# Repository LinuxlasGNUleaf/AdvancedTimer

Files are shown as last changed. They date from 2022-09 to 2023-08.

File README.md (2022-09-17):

# Advanced Timer 
This project aims to create a digital hourglass to be displayed on a LED-matrix.
The 3D-printed casing for this hourglass is fitted with dials to set the timer and change settings and a buzzer to sound an alarm tone when the timer is finished.
An Arduino Nano controls the simulation and is connected to the input dials as well.

# CAD part
The casing was designed in Autodesk Fusion 360 and consists of two main parts: The display case, featuring a 7-segment display and the LED-matrix, and the control case, housing the Arduino, power supply and input dials.
The different parts of each case and the finished casings themselves are to be 3d-printed and fitted with M3x5,7mm threaded inserts and screwed together using countersunk M3x10 and M3x14 screws.

# Assembly part
The LED-matrix consists of two daisy-chained modules using the SPI bus. These modules should be glued together (hot glue works well) and the SPI bus extended to the second module before assembly of the case starts. 
Data and power cables for the two modules inside the display casing have to be routed into the control casing via a small connector hole in the perimeter of the casings. The power supply, consisting of a 9V battery block, can be connected to the VIN/GND ports of the Arduino via the ON/OFF switch. The Arduino will transform the +9V to +5V for internal use and for external consumers like in our case. Since every breakout board used in this build requires a GND and +5V connection, a dedicated terminal for each of these is recommended. A WAGO 5-port splicing connector is sufficient and the control case has room for two (one for each of the aforementioned potentials). Once the rotary encoder (= input dial) has been connected to the power connectors as well and all data cables have been connected to the specified ports of the Arduino, it can be powered either via internal power source using the ON/OFF switch or using the exposed USB port of the Arduino. The latter will also be used to flash the program.

# Programming 
The firmware for this project was written in C++, using the platformio framework. The Arduino can be flashed without disassembling the case using the exposed USB port like mentioned above.
The behavior of the firmware can be changed in `config.h`.

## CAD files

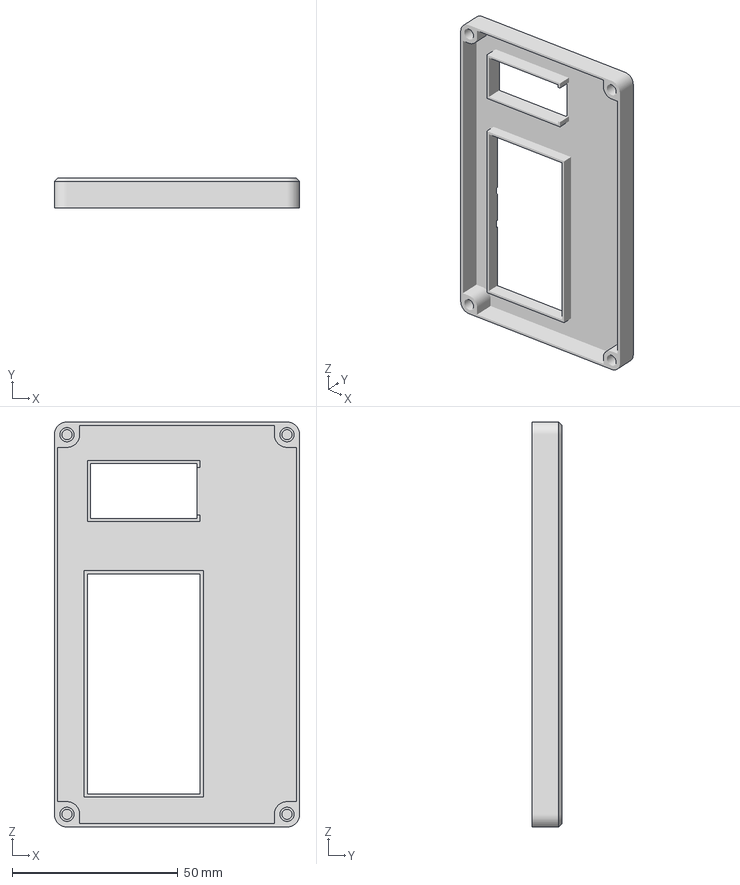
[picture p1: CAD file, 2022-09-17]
3d-print/FrontCasing.3mf
74.0 x 9.00 x 122.1 mm

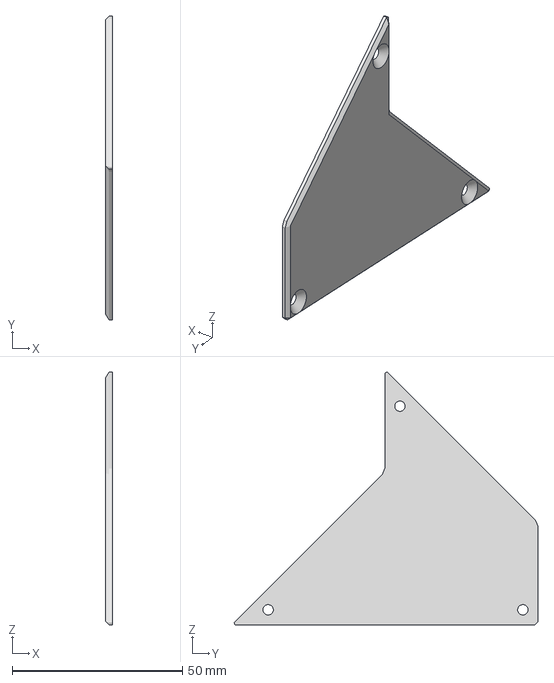
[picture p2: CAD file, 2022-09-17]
3d-print/SideCover.3mf
2.00 x 89.3 x 74.3 mm

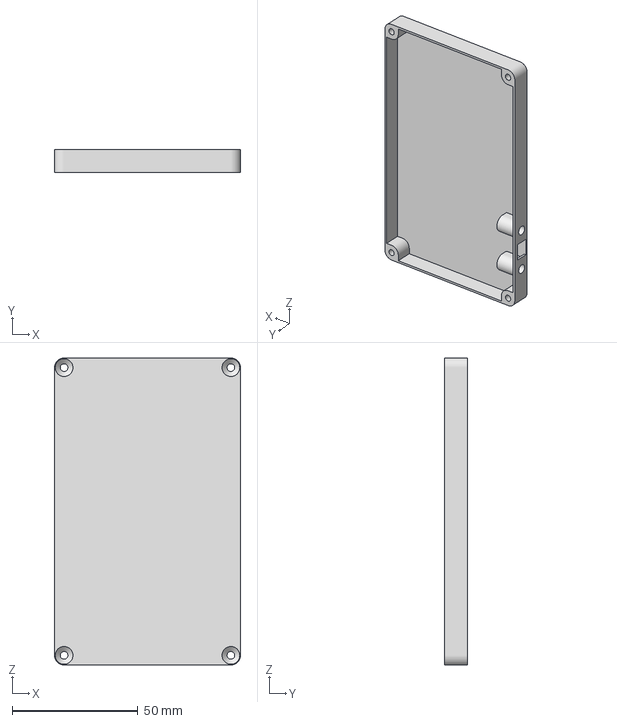
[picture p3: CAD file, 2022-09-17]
3d-print/BackCasing.3mf
74.0 x 9.00 x 122.1 mm

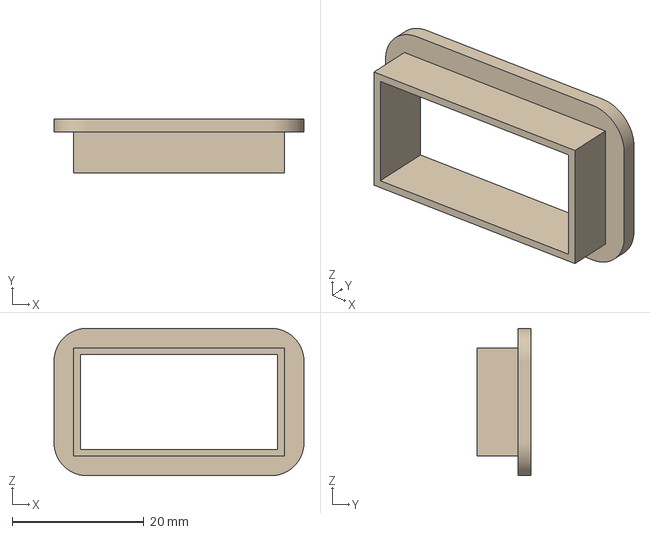
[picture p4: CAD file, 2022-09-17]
3d-print/SegmentCover.3mf
38.0 x 8.20 x 22.4 mm

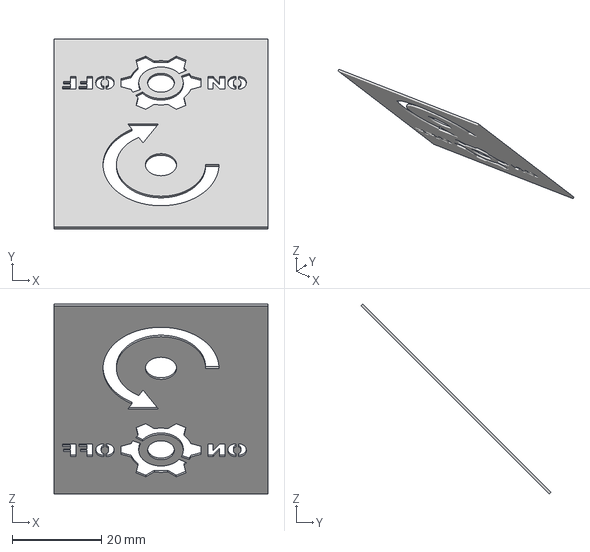
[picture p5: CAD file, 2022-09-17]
3d-print/TextCover.3mf
48.0 x 42.5 x 42.5 mm

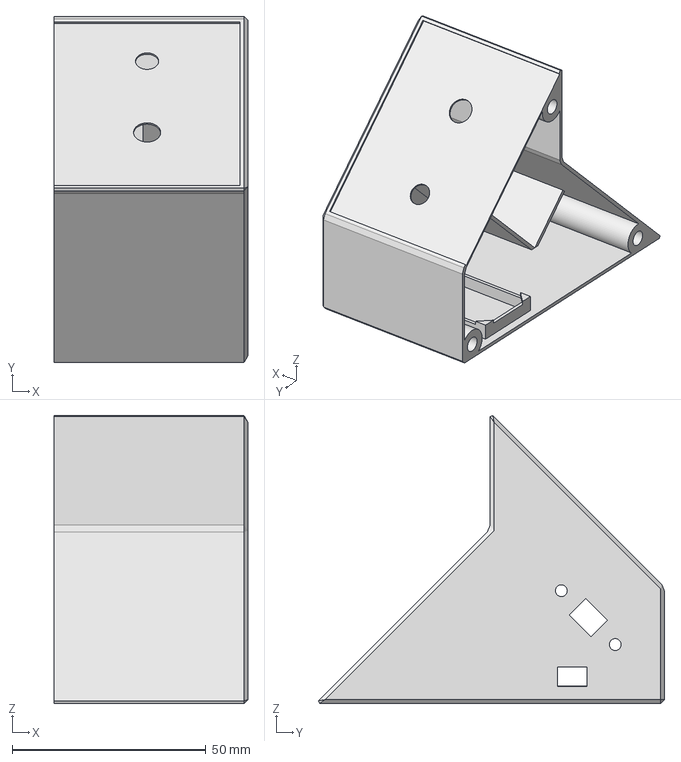
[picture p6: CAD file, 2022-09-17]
3d-print/SideHousing.3mf
50.0 x 89.3 x 74.3 mm

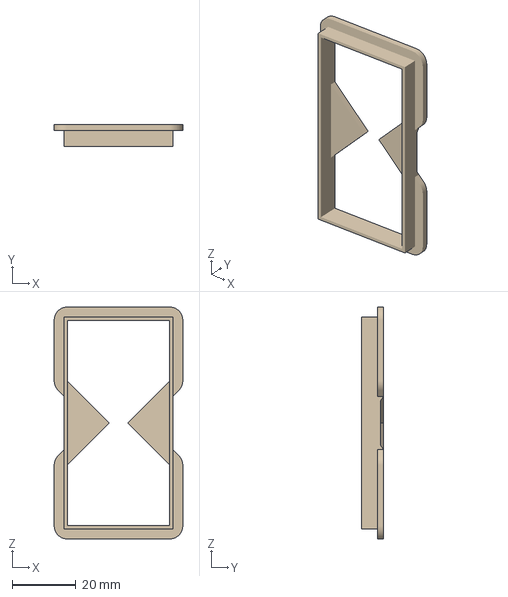
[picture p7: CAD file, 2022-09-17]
3d-print/Cover.3mf
40.2 x 7.00 x 72.5 mm

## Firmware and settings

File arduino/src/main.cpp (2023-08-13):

#include <Arduino.h>
#include <config.h>
#include <DisplayHandler.h>
#include <TimerHandler.h>

TimerHandler time_handler;
DisplayHandler display_handler;

void tickPosition()
{
  time_handler.enc->tick(); // just call tick() to check the timer_state.
}

void setup()
{
  randomSeed(analogRead(0));

#if DEBUG
  Serial.begin(SERIAL_SPEED);
#endif

  time_handler = TimerHandler();
  display_handler = DisplayHandler();

  // initialize objects & attach interrupts
  time_handler.init(tickPosition);
  display_handler.init();

  // fill upper half of hourglass
  display_handler.setup(SIM_FILL);
  while (!display_handler.is_full || !display_handler.sim_idle || time_handler.timer_state != RUNNING)
  {
    display_handler.tick(0);
    time_handler.tick();
  }
  display_handler.setup(SIM_RUNNING);
}

float progress;
void loop()
{
  while (!display_handler.is_full || !display_handler.sim_idle || time_handler.timer_state == RUNNING)
  {
    progress = time_handler.calculateTimerProgress();
    display_handler.tick(progress);
    time_handler.tick();
  }
  while (time_handler.timer_state == FINISHED)
  {
    time_handler.tick();
  }
  time_handler.resetTimerHandler();
  display_handler.setup(SIM_RELOADING);
  while (!display_handler.is_full || !display_handler.sim_idle || time_handler.timer_state != RUNNING)
  {
    display_handler.tick(0);
    time_handler.tick();
  }
  display_handler.setup(SIM_RUNNING);
}

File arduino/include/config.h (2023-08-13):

#ifndef CONFIG_H
#define CONFIG_H

// CONFIGURATION FILE
#include <MD_MAX72xx.h>
#include <TM1637Display.h>
#include <RotaryEncoder.h>
#include <EEPROM.h>
#include <hash.h>
#include <ezBuzzer.h>

// ======> PREPROCESSOR MACROS
#define DEBUG 1

#if DEBUG
#define SPRINT(msg) Serial.print(msg)
#define SPRINTLN(msg) Serial.println(msg)
#else
#define SPRINT(msg)
#define SPRINTLN(msg) 
#endif

// ======> CPP MACROS

#define INTERVAL_PASSED(start_time, interval, current_time) ((start_time + interval) < current_time)

// ======> HARDWARE / WIRING CONFIGURATION

    // ==> LED MATRIX
        
        // MATRIX SPI BUS: DIO, CLK, CS
        const int MAT_SPI_BUS[] = {11, 13, 10};

        // MODULE WIDTH
        const int MAT_WIDTH = 8;

        // MODULE COUNT
        const int MAT_MODULE_COUNT = 2;

        // MATRIX HW_TYPE
        const MD_MAX72XX::moduleType_t MAT_TYPE = MD_MAX72XX::FC16_HW;

        // MATRIX LED BRIGHTNESS
        const int MAT_BRIGHTNESS = 0;

        // MATRIX DAISY CHAIN SETUP
        /*
        *   HARDWARE LAYOUT
        *   
        * X/Y | 15 | 14 | 13 | 12 | 11 | 10 |  9 |  8 |
        *  ---+----+----+----+----+----+----+----+----+
        *  0  | ▢ | ▢ | ▢ | ▢ | ▢ | ▢ | ▢ | ▢ |
        *  1  | ▢ | ▢ | ▢ | ▢ | ▢ | ▢ | ▢ | ▢ |
        *  2  | ▢ | ▢ | ▢ | ▢ | ▢ | ▢ | ▢ | ▢ |
        *  3  | ▢ | ▢ | ▢ | ▢ | ▢ | ▢ | ▢ | ▢ |
        *  4  | ▢ | ▢ | ▢ | ▢ | ▢ | ▢ | ▢ | ▢ |
        *  5  | ▢ | ▢ | ▢ | ▢ | ▢ | ▢ | ▢ | ▢ |
        *  6  | ▢ | ▢ | ▢ | ▢ | ▢ | ▢ | ▢ | ▢ |
        *  7  | ▢ | ▢ | ▢ | ▢ | ▢ | ▢ | ▢ | ▢ |
        * 
        * X/Y |  7 |  6 |  5 |  4 |  3 |  2 |  1 |  0 |
        *  ---+----+----+----+----+----+----+----+----+
        *  0  | ▢ | ▢ | ▢ | ▢ | ▢ | ▢ | ▢ | ▢ |
        *  1  | ▢ | ▢ | ▢ | ▢ | ▢ | ▢ | ▢ | ▢ |
        *  2  | ▢ | ▢ | ▢ | ▢ | ▢ | ▢ | ▢ | ▢ |
        *  3  | ▢ | ▢ | ▢ | ▢ | ▢ | ▢ | ▢ | ▢ |
        *  4  | ▢ | ▢ | ▢ | ▢ | ▢ | ▢ | ▢ | ▢ |
        *  5  | ▢ | ▢ | ▢ | ▢ | ▢ | ▢ | ▢ | ▢ |
        *  6  | ▢ | ▢ | ▢ | ▢ | ▢ | ▢ | ▢ | ▢ |
        *  7  | ▢ | ▢ | ▢ | ▢ | ▢ | ▢ | ▢ | ▢ |
        * 
        *                    /\
        *                    ||  MAT_TRANSFORM_XY()
        *                    ||
        * 
        *   SOFTWARE LAYOUT
        *   
        * X/Y |  0 |  1 |  2 |  3 |  4 |  5 |  6 |  7 |
        *  ---+----+----+----+----+----+----+----+----+
        *  0  | ▢ | ▢ | ▢ | ▢ | ▢ | ▢ | ▢ | ▢ |
        *  1  | ▢ | ▢ | ▢ | ▢ | ▢ | ▢ | ▢ | ▢ |
        *  2  | ▢ | ▢ | ▢ | ▢ | ▢ | ▢ | ▢ | ▢ |
        *  3  | ▢ | ▢ | ▢ | ▢ | ▢ | ▢ | ▢ | ▢ |
        *  4  | ▢ | ▢ | ▢ | ▢ | ▢ | ▢ | ▢ | ▢ |
        *  5  | ▢ | ▢ | ▢ | ▢ | ▢ | ▢ | ▢ | ▢ |
        *  6  | ▢ | ▢ | ▢ | ▢ | ▢ | ▢ | ▢ | ▢ |
        *  7  | ▢ | ▢ | ▢ | ▢ | ▢ | ▢ | ▢ | ▢ |
        * 
        * X/Y |  0 |  1 |  2 |  3 |  4 |  5 |  6 |  7 |
        *  ---+----+----+----+----+----+----+----+----+
        *  8  | ▢ | ▢ | ▢ | ▢ | ▢ | ▢ | ▢ | ▢ |
        *  9  | ▢ | ▢ | ▢ | ▢ | ▢ | ▢ | ▢ | ▢ |
        * 10  | ▢ | ▢ | ▢ | ▢ | ▢ | ▢ | ▢ | ▢ |
        * 11  | ▢ | ▢ | ▢ | ▢ | ▢ | ▢ | ▢ | ▢ |
        * 12  | ▢ | ▢ | ▢ | ▢ | ▢ | ▢ | ▢ | ▢ |
        * 13  | ▢ | ▢ | ▢ | ▢ | ▢ | ▢ | ▢ | ▢ |
        * 14  | ▢ | ▢ | ▢ | ▢ | ▢ | ▢ | ▢ | ▢ |
        * 15  | ▢ | ▢ | ▢ | ▢ | ▢ | ▢ | ▢ | ▢ |
        */

        extern void MAT_TRANSFORM_XY(int *x, int *y);


        // MATRIX CONSTRAINTS
        extern uint16_t MAT_CONSTRAINTS[];
        const int MAT_FREE = 64-12; 

    // ==> 7SEG DISPLAY

        // 7SEG PINS: CLK, DIO
        const int SEG_PINS[] = {8, 9};
        
        // 7SEG LED BRIGHTNESS
        const int SEG_BRIGHTNESS = 1;

        // 7SEG DISPLAY ROTATION
        const bool SEG_ROTATED = true;


    // ==> ROTARY ENCODER

        // ENCODER PINS : CLK, DT, SW
        const int ENC_PINS[] = {2, 3, 4};
        
        // ENCODER LATCH MODE
        const RotaryEncoder::LatchMode ENC_LATCH_MODE = RotaryEncoder::LatchMode::FOUR3;
        
        // ENCODER POSITIVE DIRECTION: CW = CLOCKWISE
        const bool ENC_CW_IS_POSITIVE = true;


    // ==> BUZZER

        // BUZZER PIN
        const int BUZZER_PIN = 7;
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

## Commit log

2022-03-09 switched rotary encoder lib, added interrupts and interrupt locks
2022-03-09 switched to byte fields for ease of communication with the board
2022-03-12 fix display not working correctly, fix custom messages not displaying
    [TimerHandler.cpp]
2022-03-12 extend timer fsm, implement pause and reset functionality
    [TimerHandler.cpp, main.cpp]
2022-03-19 implement end state and reset
    [TimerHandler.cpp, main.cpp]
2022-03-19 add buzzer for audio feedback for rotary encoder
    [TimerHandler.cpp, main.cpp]
2022-04-23 handle edge case for clicking sound
2022-04-23 makes the melody play at correct length, removes debug msgs
    [TimerHandler.cpp, main.cpp]
2022-09-17 restructures repo, adds README, adds 3mf files
    [BackCasing.3mf, Cover.3mf, FrontCasing.3mf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]
2022-09-19 creates environments for Arduinos with both old and new bootloaders
2022-09-20 rewrites TimerHandler, SandSimulation currently not integrated
2023-08-13 fix STOP functionality, now using WDT instead
    [TimerHandler.cpp]
2023-08-13 fix edge case where stored values are loaded even when modes differ
    [TimerHandler.cpp]
2024-09-16 Add schematic
    [AdvancedTimer.fzz]
